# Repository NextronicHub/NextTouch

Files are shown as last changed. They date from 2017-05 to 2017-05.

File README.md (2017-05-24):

# Nextronic NextTouch

The NextTouch is a microcontroller board based on the ATmega32u4. It has 20 digital input/output pins (of which 7 can be used as PWM outputs and 12 as analog inputs), a 16 MHz crystal oscillator, a micro USB connection, and a ICSP header. It contains everything needed to support the microcontroller; simply connect it to a computer with a USB cable and get started. 

the ATmega32u4 has built-in USB communication, eliminating the need for a secondary processor. This allows the NextTouch to appear to a connected computer as a mouse and keyboard, in addition to a virtual (CDC) serial / COM port. It also has other implications for the behavior of the board.

Using the NextTouch you can make anything into a key just by connecting a few alligator clips. This allows you to hook up all kinds of fun things as an input.
The NextTouch uses high resistance switching to detect when you've made a connection even through materials that aren't very conductive (like leaves, pasta or people).

## Features

  ATmega32U4 microcontroller w<br />
  Input voltage 5V<br />
  0-5V outputs<br />
  18 Digital capacitive inputs Pins <br />
  6 Analog Inputs<br />
  I2C, UART and SPI<br />
  32k Flash Memory<br />
  16MHz Clock Speed<br />

<br />
<br />

Nextronic Product page:[NextTouch](http://nextronic.ma/product/nextTouch/).

you can by it at: [makershop.ma](http://makershop.ma/).

## Repository Contents

/Hardware - Design files (.brd, .sch)  
/Firmware - bootloader  
/Documentation - datasheet and examples

## Product Versions

NextTouch_V1 first release

## License Information

The hardware is released under [Creative Commons ShareAlike 4.0 International](https://creativecommons.org/licenses/by-sa/4.0/).

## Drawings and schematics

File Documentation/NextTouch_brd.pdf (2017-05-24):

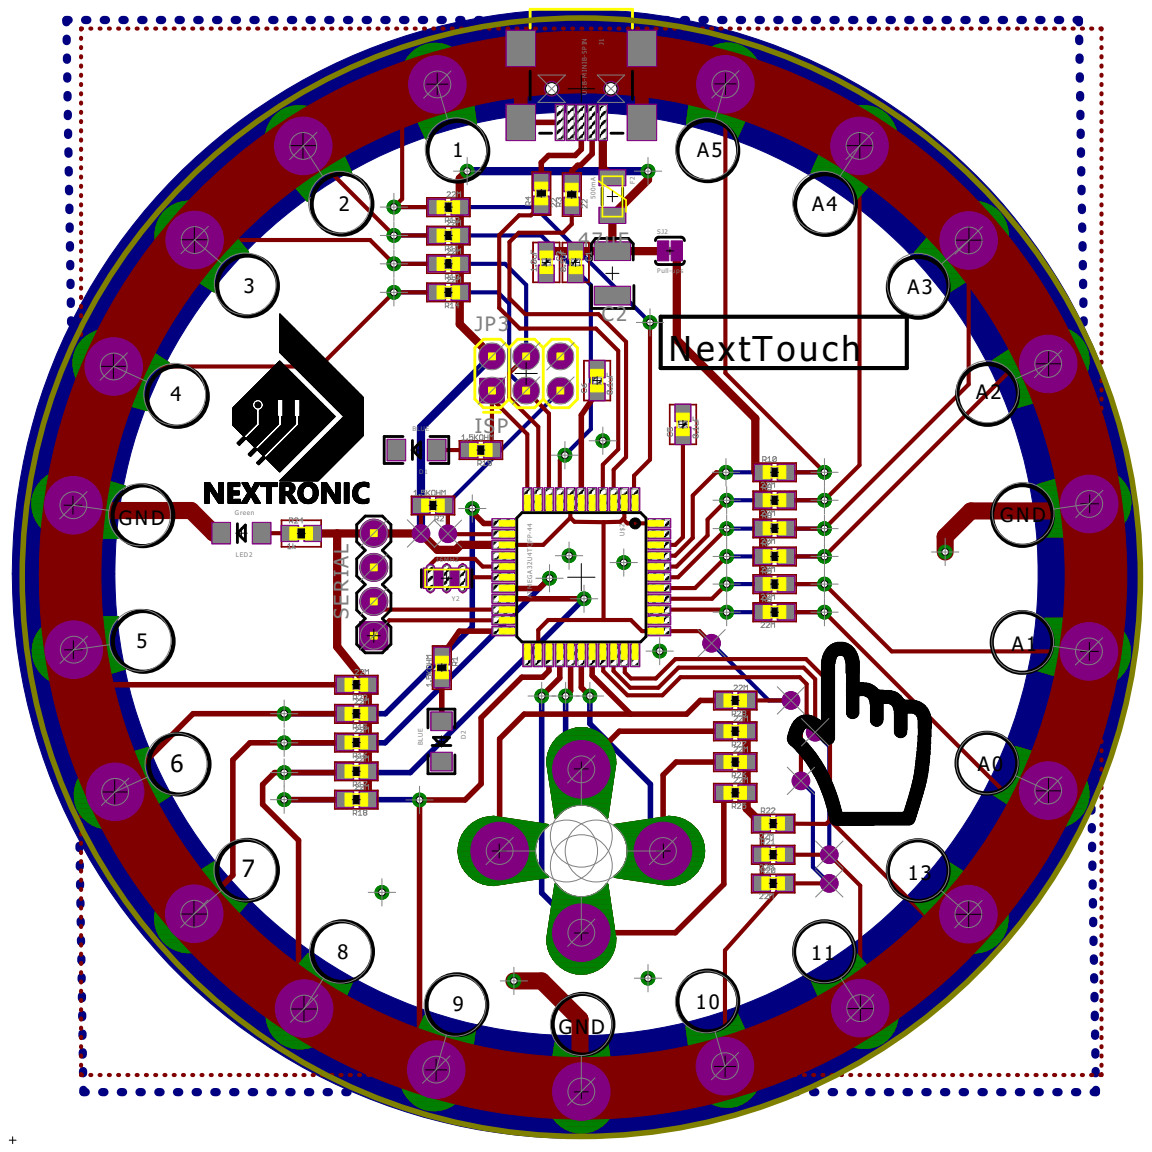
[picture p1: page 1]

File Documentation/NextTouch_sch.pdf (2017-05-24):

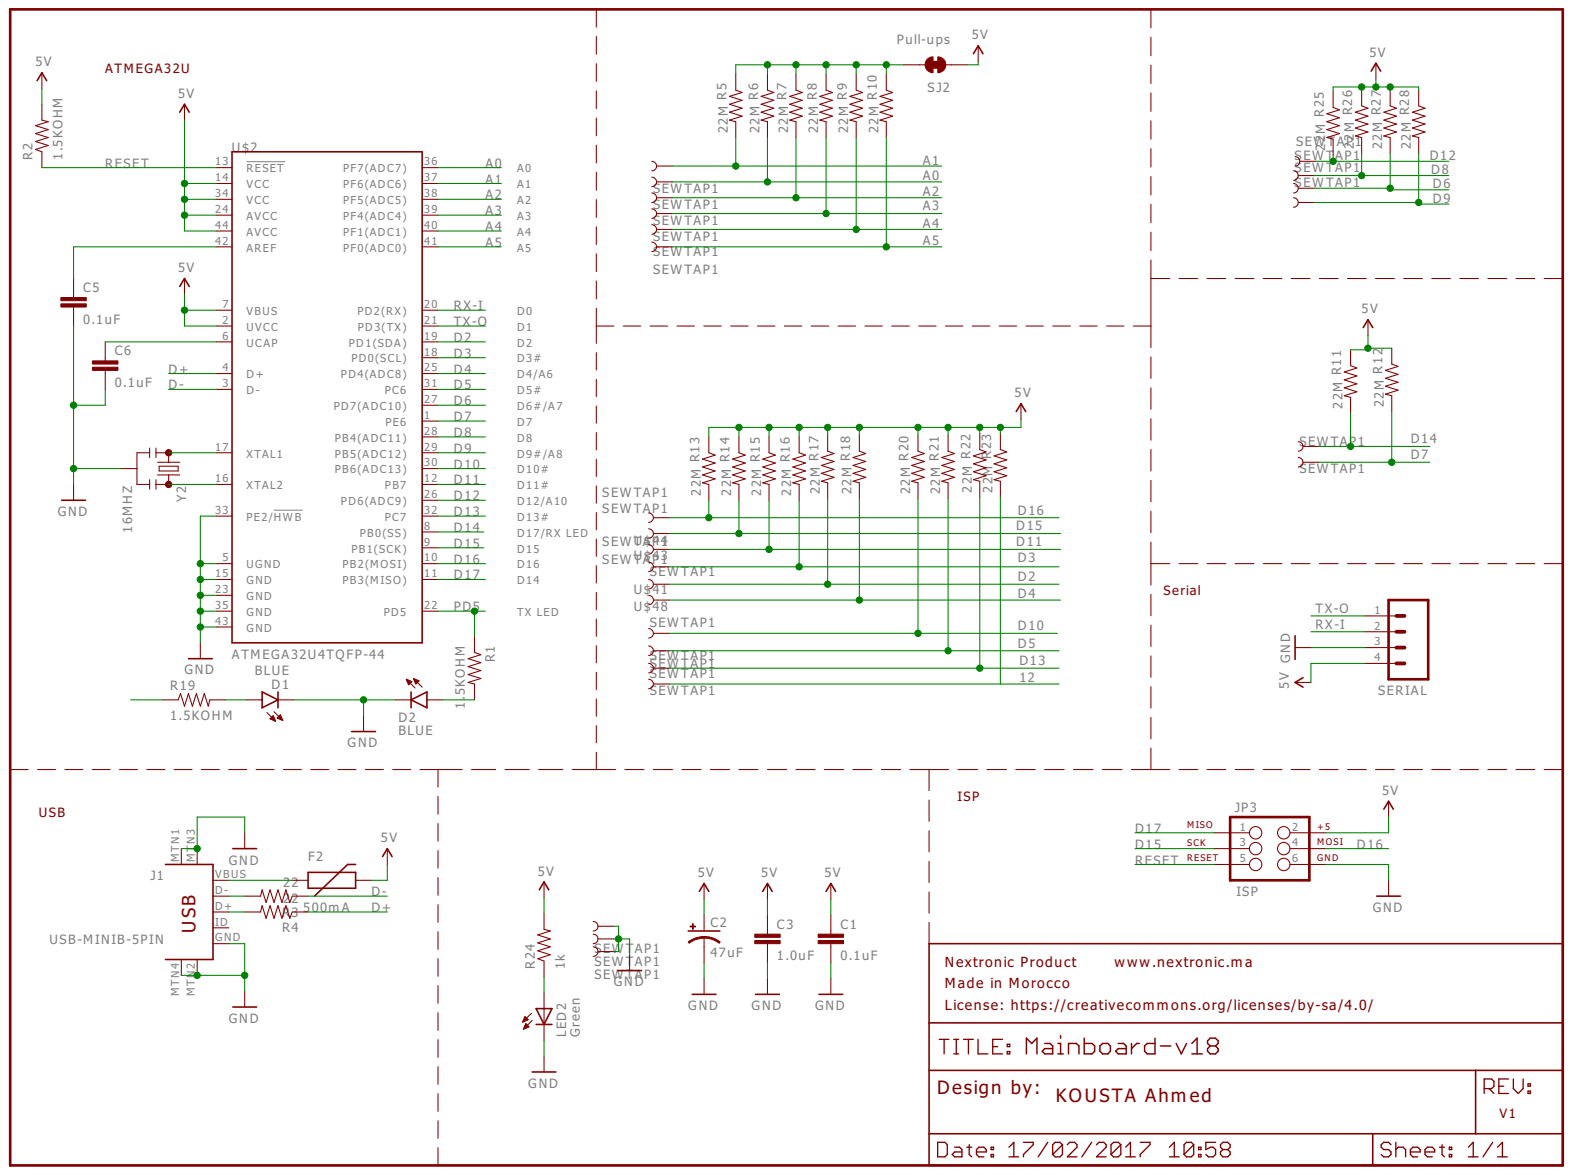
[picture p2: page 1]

SEW TAP1 SEW TAP1

SEW TAP1

License: https://creativecommons.org/licenses/by-sa/4.0/

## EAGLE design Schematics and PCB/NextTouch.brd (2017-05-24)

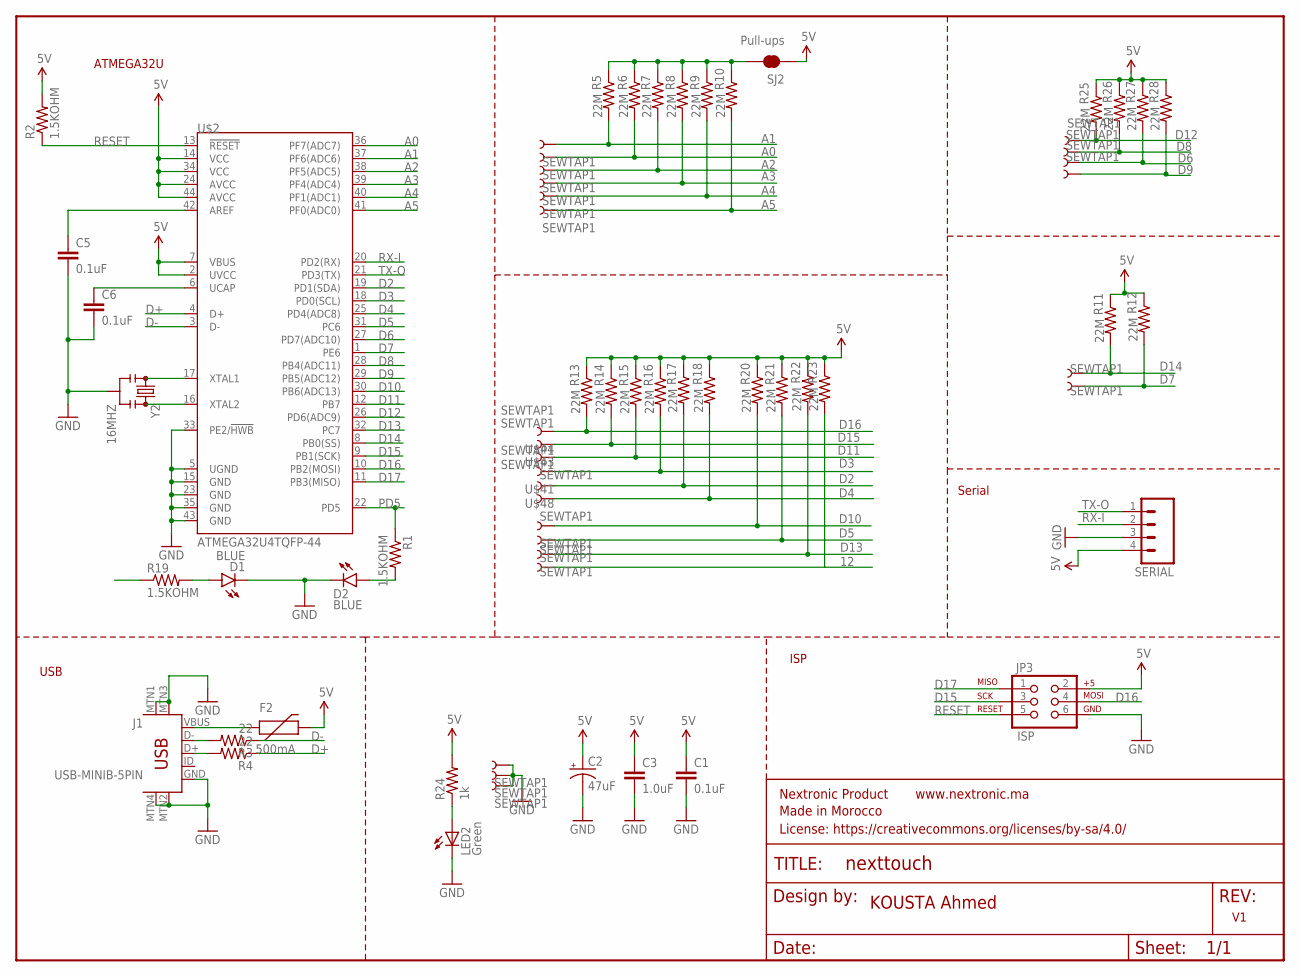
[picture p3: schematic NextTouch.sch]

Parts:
C1, C5, C6: 0.1uF; 0603
C2: 47uF; EIA3528
C3: 1.0uF; 0603
D1, D2: BLUE; LED-1206
F2: 500mA; PTC-1206
FRAME1: FRAME-LETTER; CREATIVE_COMMONS
GND: SEWTAP1; PETAL-LONG-1
J1: USB-MINIB-5PIN; USB-MINIB
JP3: ISP; 2X3-NS
LED2: Green; LED-1206-NO_SILK
R1, R2, R19: 1.5KOHM; 0603
R3, R4: 22; 0603
R5, R6, R7, R8, R9, R10, R11, R12, R13, R14, R15, R16, R17, R18, R20, R21, R22, R23, R25, R26, R27, R28: 22M; 0603
R24: 1k; 0603-RES
SERIAL: M04PTH; 1X04
SJ2: Pull-ups; SJ_2S-TRACE
U$2: ATMEGA32U4TQFP-44; TQFP44
U$3, U$4, U$5, U$6, U$7, U$30, U$31, U$32, U$33, U$34, U$35, U$36, U$37, U$38, U$39, U$40, U$41, U$42, U$43, U$44, U$45, U$46, U$48, U$51: SEWTAP1; PETAL-LONG-1
Y2: 16MHZ; RESONATOR-SMD

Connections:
5V: C1.1, C2.A (+), C3.1, F2.2, JP3.2, R2.2, R11.1, R12.1, R13.1, R14.1, R15.1, R16.1, R17.1, R18.1, R20.1, R21.1, R22.1, R23.1, R24.2, R25.1, R26.1, R27.1, R28.1, SERIAL.4, SJ2.1, U$2.2 (UVCC), U$2.7 (VBUS), U$2.14 (VCC), U$2.24 (AVCC), U$2.34 (VCC), U$2.44 (AVCC)
12: R23.2, U$51.1
A0: R6.2, U$2.36 (PF7(ADC7)), U$40.1
A1: R5.2, U$2.37 (PF6(ADC6)), U$4.1
A2: R7.2, U$2.38 (PF5(ADC5)), U$31.1
A3: R8.2, U$2.39 (PF4(ADC4)), U$32.1
A4: R9.2, U$2.40 (PF1(ADC1)), U$33.1
A5: R10.2, U$2.41 (PF0(ADC0)), U$34.1
D2: R17.2, U$2.19 (PD1(SDA)), U$48.1
D3: R16.2, U$2.18 (PD0(SCL)), U$41.1
D4: R18.2, U$2.25 (PD4(ADC8)), U$35.1
D5: R21.2, U$2.31 (PC6), U$38.1
D6: R27.2, U$2.27 (PD7(ADC10)), U$7.1
D7: R12.2, U$2.1 (PE6), U$46.1
D8: R26.2, U$2.28 (PB4(ADC11)), U$6.1
D9: R28.2, U$2.29 (PB5(ADC12)), U$3.1
D10: R20.2, U$2.30 (PB6(ADC13)), U$37.1
D11: R15.2, U$2.12 (PB7), U$42.1
D12: R25.2, U$2.26 (PD6(ADC9)), U$5.1
D13: R22.2, U$2.32 (PC7), U$39.1
D14: R11.2, U$2.8 (PB0(SS)), U$45.1
D15: JP3.3, R14.2, U$2.9 (PB1(SCK)), U$43.1
D16: JP3.4, R13.2, U$2.10 (PB2(MOSI)), U$44.1
D17: JP3.1, R19.1, U$2.11 (PB3(MISO))
D+: R4.1, U$2.4 (D+)
D-: R3.1, U$2.3 (D-)
GND: C1.2, C2.C (-), C3.2, C5.2, C6.2, D1.C, D2.C, GND.1, J1.GND, J1.MTN1 (MTN2), J1.MTN2 (MTN3), J1.MTN3 (MTN1), J1.MTN4, JP3.6, LED2.C, SERIAL.3, U$2.5 (UGND), U$2.15 (GND), U$2.23 (GND), U$2.33 (PE2/!HWB), U$2.35 (GND), U$2.43 (GND), U$30.1, U$36.1, Y2.2
unnamed: D2.A, R1.2
unnamed: LED2.A, R24.1
unnamed: D1.A, R19.2
unnamed: U$2.17 (XTAL1), Y2.1
unnamed: U$2.16 (XTAL2), Y2.3
unnamed: C5.1, U$2.42 (AREF)
unnamed: R5.1, R6.1, R7.1, R8.1, R9.1, R10.1, SJ2.2
unnamed: F2.1, J1.VBUS
unnamed: C6.1, U$2.6 (UCAP)
unnamed: J1.D-, R3.2
unnamed: J1.D+, R4.2
PD5: R1.1, U$2.22 (PD5)
RESET: JP3.5, R2.1, U$2.13 (!RESET)
RX-I: SERIAL.2, U$2.20 (PD2(RX))
TX-O: SERIAL.1, U$2.21 (PD3(TX))

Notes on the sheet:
ATMEGA32U
USB
KOUSTA Ahmed
ISP
Serial

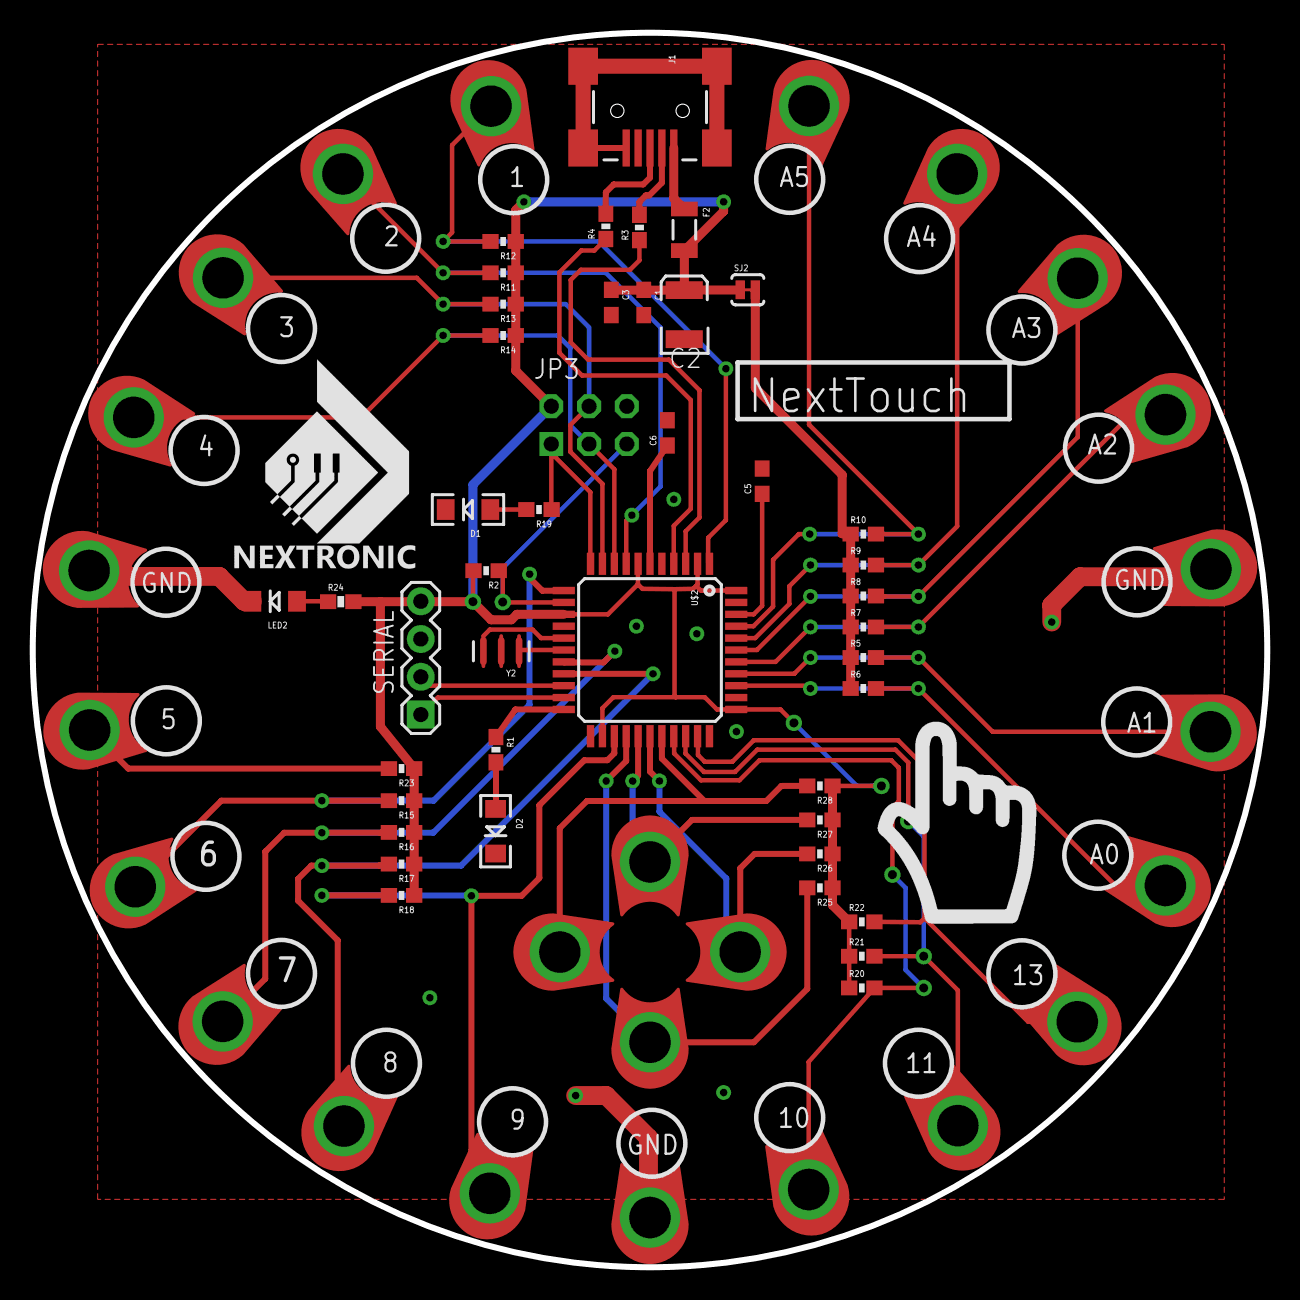
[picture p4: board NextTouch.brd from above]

Board: 2 copper layers, 83.0 x 83.0 mm, 69 parts (0 on the bottom side), 42 nets.

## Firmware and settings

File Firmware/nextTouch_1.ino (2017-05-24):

/*
 ************************************************
 ************** NextTouch *********************
 ************************************************
 
 /////////////////////////////////////////////////
 /////////////HOW TO EDIT THE KEYS ///////////////
 /////////////////////////////////////////////////
 - Edit keys in the settings.h file
 - that file should be open in a tab above (in Arduino IDE)
 - more instructions are in that file
 
 ////////////////////////////////////////////////
 //////// NextTouch FIRMWARE v1.2 /////////////
 ////////////////////////////////////////////////
 by: Ahmed KOUSTA
 Nextronic.ma
 current release: 22/5/2017
 NextTouch FIRMWARE based on the makey makey FIRMWARE v1.4
 */

/////////////////////////
// DEBUG DEFINITIONS ////               
/////////////////////////
//#define DEBUG
//#define DEBUG2 
//#define DEBUG3 
//#define DEBUG_TIMING
//#define DEBUG_MOUSE
//#define DEBUG_TIMING2

////////////////////////
// DEFINED CONSTANTS////
////////////////////////

#define BUFFER_LENGTH    3     // 3 bytes gives us 24 samples
#define NUM_INPUTS       18    // 6 on the front + 12 on the back
//#define TARGET_LOOP_TIME 694   // (1/60 seconds) / 24 samples = 694 microseconds per sample 
//#define TARGET_LOOP_TIME 758  // (1/55 seconds) / 24 samples = 758 microseconds per sample 
#define TARGET_LOOP_TIME 744  // (1/56 seconds) / 24 samples = 744 microseconds per sample 

// id numbers for mouse movement inputs (used in settings.h)
#define MOUSE_MOVE_UP       -1 
#define MOUSE_MOVE_DOWN     -2
#define MOUSE_MOVE_LEFT     -3
#define MOUSE_MOVE_RIGHT    -4

#include <Keyboard.h>
#include <Mouse.h>
#include "settings.h"

/////////////////////////
// STRUCT ///////////////
/////////////////////////
typedef struct {
  byte pinNumber;
  int keyCode;
  byte measurementBuffer[BUFFER_LENGTH]; 
  boolean oldestMeasurement;
  byte bufferSum;
  boolean pressed;
  boolean prevPressed;
  boolean isMouseMotion;
  boolean isMouseButton;
  boolean isKey;
} 
MakeyMakeyInput;

MakeyMakeyInput inputs[NUM_INPUTS];

///////////////////////////////////
// VARIABLES //////////////////////
///////////////////////////////////
int bufferIndex = 0;
byte byteCounter = 0;
byte bitCounter = 0;
int mouseMovementCounter = 0; // for sending mouse movement events at a slower interval

int pressThreshold;
int releaseThreshold;
boolean inputChanged;

int mouseHoldCount[NUM_INPUTS]; // used to store mouse movement hold data

// Pin Numbers
// input pin numbers for kickstarter production board
int pinNumbers[NUM_INPUTS] = {
  6, 12, 9, 8,                         // Arrows pinout setup
  7, 15, 11, 3, 2, 4, 10, 5, 13,       // alphabets pinout setup
  //A0, A1, A2, A3, A4, A5             // mouse pinout setup
};

// input status LED pin numbers
const int inputLED_a = 9;
const int inputLED_b = 10;
const int inputLED_c = 11;
const int outputK = 14;
const int outputM = 16;
byte ledCycleCounter = 0;

// timing
int loopTime = 0;
int prevTime = 0;
int loopCounter = 0;


///////////////////////////
// FUNCTIONS //////////////
///////////////////////////
void initializeArduino();
void initializeInputs();
void updateMeasurementBuffers();
void updateBufferSums();
void updateBufferIndex();
void updateInputStates();
void sendMouseButtonEvents();
void sendMouseMovementEvents();
void addDelay();
void cycleLEDs();
void danceLeds();
void updateOutLEDs();

//////////////////////
// SETUP /////////////
//////////////////////
void setup() 
{
  initializeArduino();
  initializeInputs();
  danceLeds();
}

////////////////////
// MAIN LOOP ///////
////////////////////
void loop() 
{
  updateMeasurementBuffers();
  updateBufferSums();
  updateBufferIndex();
  updateInputStates();
  sendMouseButtonEvents();
  sendMouseMovementEvents();
  cycleLEDs();
  updateOutLEDs();
  addDelay();
}

//////////////////////////
// INITIALIZE ARDUINO
//////////////////////////
void initializeArduino() {
#ifdef DEBUG
  Serial.begin(9600);  // Serial for debugging
#endif

  /* Set up input pins 
   DEactivate the internal pull-ups, since we're using external resistors */
  for (int i=0; i<NUM_INPUTS; i++)
  {
    pinMode(pinNumbers[i], INPUT);
    digitalWrite(pinNumbers[i], LOW);
  }

  pinMode(inputLED_a, INPUT);
  pinMode(inputLED_b, INPUT);
  pinMode(inputLED_c, INPUT);
  digitalWrite(inputLED_a, LOW);
  digitalWrite(inputLED_b, LOW);
  digitalWrite(inputLED_c, LOW);

  pinMode(outputK, OUTPUT);
  pinMode(outputM, OUTPUT);
  digitalWrite(outputK, LOW);
  digitalWrite(outputM, LOW);


#ifdef DEBUG
  delay(4000); // allow us time to reprogram in case things are freaking out
#endif

  Keyboard.begin();
  Mouse.begin();
}

///////////////////////////
// INITIALIZE INPUTS
///////////////////////////
void initializeInputs() {

  float thresholdPerc = SWITCH_THRESHOLD_OFFSET_PERC;
  float thresholdCenterBias = SWITCH_THRESHOLD_CENTER_BIAS/50.0;
  float pressThresholdAmount = (BUFFER_LENGTH * 8) * (thresholdPerc / 100.0);
  float thresholdCenter = ( (BUFFER_LENGTH * 8) / 2.0 ) * (thresholdCenterBias);
  pressThreshold = int(thresholdCenter + pressThresholdAmount);
  releaseThreshold = int(thresholdCenter - pressThresholdAmount);

#ifdef DEBUG
  Serial.println(pressThreshold);
  Serial.println(releaseThreshold);
#endif

  for (int i=0; i<NUM_INPUTS; i++) {
    inputs[i].pinNumber = pinNumbers[i];
    inputs[i].keyCode = keyCodes[i];

    for (int j=0; j<BUFFER_LENGTH; j++) {
      inputs[i].measurementBuffer[j] = 0;
    }
    inputs[i].oldestMeasurement = 0;
    inputs[i].bufferSum = 0;

    inputs[i].pressed = false;
    inputs[i].prevPressed = false;

    inputs[i].isMouseMotion = false;
    inputs[i].isMouseButton = false;
    inputs[i].isKey = false;

    if (inputs[i].keyCode < 0) {
#ifdef DEBUG_MOUSE
      Serial.println("GOT IT");  
#endif

      inputs[i].isMouseMotion = true;
    } 
    else if ((inputs[i].keyCode == MOUSE_LEFT) || (inputs[i].keyCode == MOUSE_RIGHT)) {
      inputs[i].isMouseButton = true;
    } 
    else {
      inputs[i].isKey = true;
    }
#ifdef DEBUG
    Serial.println(i);
#endif

  }
}


//////////////////////////////
// UPDATE MEASUREMENT BUFFERS
//////////////////////////////
void updateMeasurementBuffers() {

  for (int i=0; i<NUM_INPUTS; i++) {

    // store the oldest measurement, which is the one at the current index,
    // before we update it to the new one 
    // we use oldest measurement in updateBufferSums
    byte currentByte = inputs[i].measurementBuffer[byteCounter];
    inputs[i].oldestMeasurement = (currentByte >> bitCounter) & 0x01; 

    // make the new measurement
    boolean newMeasurement = digitalRead(inputs[i].pinNumber);

    // invert so that true means the switch is closed
    newMeasurement = !newMeasurement; 

    // store it    
    if (newMeasurement) {
      currentByte |= (1<<bitCounter);
    } 
    else {
      currentByte &= ~(1<<bitCounter);
    }
    inputs[i].measurementBuffer[byteCounter] = currentByte;
  }
}

///////////////////////////
// UPDATE BUFFER SUMS
///////////////////////////
void updateBufferSums() {

  // the bufferSum is a running tally of the entire measurementBuffer
  // add the new measurement and subtract the old one

  for (int i=0; i<NUM_INPUTS; i++) {
    byte currentByte = inputs[i].measurementBuffer[byteCounter];
    boolean currentMeasurement = (currentByte >> bitCounter) & 0x01; 
    if (currentMeasurement) {
      inputs[i].bufferSum++;
    }
    if (inputs[i].oldestMeasurement) {
      inputs[i].bufferSum--;
    }
  }  
}

///////////////////////////
// UPDATE BUFFER INDEX
///////////////////////////
void updateBufferIndex() {
  bitCounter++;
  if (bitCounter == 8) {
    bitCounter = 0;
    byteCounter++;
    if (byteCounter == BUFFER_LENGTH) {
      byteCounter = 0;
    }
  }
}

///////////////////////////
// UPDATE INPUT STATES
///////////////////////////
void updateInputStates() {
  inputChanged = false;
  for (int i=0; i<NUM_INPUTS; i++) {
    inputs[i].prevPressed = inputs[i].pressed; // store previous pressed state (only used for mouse buttons)
    if (inputs[i].pressed) {
      if (inputs[i].bufferSum < releaseThreshold) {  
        inputChanged = true;
        inputs[i].pressed = false;
        if (inputs[i].isKey) {
          Keyboard.release(inputs[i].keyCode);
        }
        if (inputs[i].isMouseMotion) {  
          mouseHoldCount[i] = 0;  // input becomes released, reset mouse hold
        }
      }
      else if (inputs[i].isMouseMotion) {  
        mouseHoldCount[i]++; // input remains pressed, increment mouse hold
      }
    } 
    else if (!inputs[i].pressed) {
      if (inputs[i].bufferSum > pressThreshold) {  // input becomes pressed
        inputChanged = true;
        inputs[i].pressed = true; 
        if (inputs[i].isKey) {
          Keyboard.press(inputs[i].keyCode);
        }
      }
    }
  }
#ifdef DEBUG3
  if (inputChanged) {
    Serial.println("change");
  }
#endif
}

/*
///////////////////////////
 // SEND KEY EVENTS (obsolete, used in versions with pro micro bootloader)
 ///////////////////////////
 void sendKeyEvents() {
 if (inputChanged) {
 KeyReport report = {
 0                                                        };
 for (int i=0; i<6; i++) {
 report.keys[i] = 0;
 } 
 int count = 0;
 for (int i=0; i<NUM_INPUTS; i++) {
 if (inputs[i].pressed && (count < 6)) {
 report.keys[count] = inputs[i].keyCode;
 
 #ifdef DEBUG3
 Serial.println(report.keys[count]);
 #endif
 
 count++;        
 }
 }
 if (count > 0) {
 report.modifiers = 0x00;
 report.reserved = 1;
 Keyboard.sendReport(&report);
 } 
 else {
 report.modifiers = 0x00;
 report.reserved = 0;
 Keyboard.sendReport(&report);
 }      
 } 
 else {
 // might need a delay here to compensate for the time it takes to send keyreport
 }
 }
 */

/////////////////////////////
// SEND MOUSE BUTTON EVENTS 
/////////////////////////////
void sendMouseButtonEvents() {
  if (inputChanged) {
    for (int i=0; i<NUM_INPUTS; i++) {
      if (inputs[i].isMouseButton) {
        if (inputs[i].pressed) {
          if (inputs[i].keyCode == MOUSE_LEFT) {
            Mouse.press(MOUSE_LEFT);
          } 
          if (inputs[i].keyCode == MOUSE_RIGHT) {
            Mouse.press(MOUSE_RIGHT);
          } 
        } 
        else if (inputs[i].prevPressed) {
          if (inputs[i].keyCode == MOUSE_LEFT) {
            Mouse.release(MOUSE_LEFT);
          } 
          if (inputs[i].keyCode == MOUSE_RIGHT) {
            Mouse.release(MOUSE_RIGHT);
          }           
        }
      }
    }
  }
}

//////////////////////////////
// SEND MOUSE MOVEMENT EVENTS
//////////////////////////////
void sendMouseMovementEvents() {
  byte right = 0;
  byte left = 0;
  byte down = 0;
  byte up = 0;
  byte horizmotion = 0;
  byte vertmotion = 0;

  mouseMovementCounter++;
  mouseMovementCounter %= MOUSE_MOTION_UPDATE_INTERVAL;
  if (mouseMovementCounter == 0) {
    for (int i=0; i<NUM_INPUTS; i++) {
#ifdef DEBUG_MOUSE
      //  Serial.println(inputs[i].isMouseMotion);  
#endif

      if (inputs[i].isMouseMotion) {
        if (inputs[i].pressed) {
          if (inputs[i].keyCode == MOUSE_MOVE_UP) {
            // JL Changes (x4): now update to 1 + a hold factor, constrained between 1 and mouse max movement speed
            up=constrain(1+mouseHoldCount[i]/MOUSE_RAMP_SCALE, 1, MOUSE_MAX_PIXELS);
          }  
          if (inputs[i].keyCode == MOUSE_MOVE_DOWN) {
            down=constrain(1+mouseHoldCount[i]/MOUSE_RAMP_SCALE, 1, MOUSE_MAX_PIXELS);
          }  
          if (inputs[i].keyCode == MOUSE_MOVE_LEFT) {
            left=constrain(1+mouseHoldCount[i]/MOUSE_RAMP_SCALE, 1, MOUSE_MAX_PIXELS);
          }  
          if (inputs[i].keyCode == MOUSE_MOVE_RIGHT) {
            right=constrain(1+mouseHoldCount[i]/MOUSE_RAMP_SCALE, 1, MOUSE_MAX_PIXELS);
          }  
        }
      }
    }

    // diagonal scrolling and left/right cancellation
    if(left > 0)
    {
      if(right > 0)
      {
        horizmotion = 0; // cancel horizontal motion because left and right are both pushed
      }
      else
      {
        horizmotion = -left; // left yes, right no
      }
    }
    else
    {
      if(right > 0)
      {
        horizmotion = right; // right yes, left no
      }
    }

    if(down > 0)
    {
      if(up > 0)
      {
        vertmotion = 0; // cancel vertical motion because up and down are both pushed
      }
      else
      {
        vertmotion = down; // down yes, up no
      }
    }
    else
    {
      if (up > 0)
      {
        vertmotion = -up; // up yes, down no
      }
    }
    // now move the mouse
    if( !((horizmotion == 0) && (vertmotion==0)) )
    {
      Mouse.move(horizmotion * PIXELS_PER_MOUSE_STEP, vertmotion * PIXELS_PER_MOUSE_STEP);
    }
  }
}

///////////////////////////
// ADD DELAY
///////////////////////////
void addDelay() {

  loopTime = micros() - prevTime;
  if (loopTime < TARGET_LOOP_TIME) {
    int wait = TARGET_LOOP_TIME - loopTime;
    delayMicroseconds(wait);
  }

  prevTime = micros();

#ifdef DEBUG_TIMING
  if (loopCounter == 0) {
    int t = micros()-prevTime;
    Serial.println(t);
  }
  loopCounter++;
  loopCounter %= 999;
#endif

}

///////////////////////////
// CYCLE LEDS
///////////////////////////
void cycleLEDs() {
  pinMode(inputLED_a, INPUT);
  pinMode(inputLED_b, INPUT);
  pinMode(inputLED_c, INPUT);
  digitalWrite(inputLED_a, LOW);
  digitalWrite(inputLED_b, LOW);
  digitalWrite(inputLED_c, LOW);

  ledCycleCounter++;
  ledCycleCounter %= 6;

  if ((ledCycleCounter == 0) && inputs[0].pressed) {
    pinMode(inputLED_a, INPUT);
    digitalWrite(inputLED_a, HIGH);
    pinMode(inputLED_b, OUTPUT);
    digitalWrite(inputLED_b, HIGH);
    pinMode(inputLED_c, OUTPUT);
    digitalWrite(inputLED_c, LOW);
  }
  if ((ledCycleCounter == 1) && inputs[1].pressed) {
    pinMode(inputLED_a, OUTPUT);
    digitalWrite(inputLED_a, HIGH);
    pinMode(inputLED_b, OUTPUT);
    digitalWrite(inputLED_b, LOW);
    pinMode(inputLED_c, INPUT);
    digitalWrite(inputLED_c, LOW);

  }
  if ((ledCycleCounter == 2) && inputs[2].pressed) {
    pinMode(inputLED_a, OUTPUT);
    digitalWrite(inputLED_a, LOW);
    pinMode(inputLED_b, OUTPUT);
    digitalWrite(inputLED_b, HIGH);
    pinMode(inputLED_c, INPUT);
    digitalWrite(inputLED_c, LOW);
  }
  if ((ledCycleCounter == 3) && inputs[3].pressed) {
    pinMode(inputLED_a, INPUT);
    digitalWrite(inputLED_a, LOW);
    pinMode(inputLED_b, OUTPUT);
    digitalWrite(inputLED_b, LOW);
    pinMode(inputLED_c, OUTPUT);
    digitalWrite(inputLED_c, HIGH);
  }
  if ((ledCycleCounter == 4) && inputs[4].pressed) {
    pinMode(inputLED_a, OUTPUT);
    digitalWrite(inputLED_a, LOW);
    pinMode(inputLED_b, INPUT);
    digitalWrite(inputLED_b, LOW);
    pinMode(inputLED_c, OUTPUT);
    digitalWrite(inputLED_c, HIGH);
  }
  if ((ledCycleCounter == 5) && inputs[5].pressed) {
    pinMode(inputLED_a, OUTPUT);
    digitalWrite(inputLED_a, HIGH);
    pinMode(inputLED_b, INPUT);
    digitalWrite(inputLED_b, LOW);
    pinMode(inputLED_c, OUTPUT);
    digitalWrite(inputLED_c, LOW);
  }

}

///////////////////////////
// DANCE LEDS
///////////////////////////
void danceLeds()
{
  int delayTime = 50;
  int delayTime2 = 100;

  // CIRCLE
  for(int i=0; i<4; i++)
  {
    // UP
    pinMode(inputLED_a, INPUT);
    digitalWrite(inputLED_a, HIGH);
    pinMode(inputLED_b, OUTPUT);
    digitalWrite(inputLED_b, HIGH);
    pinMode(inputLED_c, OUTPUT);
    digitalWrite(inputLED_c, LOW);
    delay(delayTime);

    //RIGHT
    pinMode(inputLED_a, INPUT);
    digitalWrite(inputLED_a, LOW);
    pinMode(inputLED_b, OUTPUT);
    digitalWrite(inputLED_b, LOW);
    pinMode(inputLED_c, OUTPUT);
    digitalWrite(inputLED_c, HIGH);
    delay(delayTime);


    // DOWN
    pinMode(inputLED_a, OUTPUT);
    digitalWrite(inputLED_a, HIGH);
    pinMode(inputLED_b, OUTPUT);
    digitalWrite(inputLED_b, LOW);
    pinMode(inputLED_c, INPUT);
    digitalWrite(inputLED_c, LOW);
    delay(delayTime);

    // LEFT
    pinMode(inputLED_a, OUTPUT);
    digitalWrite(inputLED_a, LOW);
    pinMode(inputLED_b, OUTPUT);    
    digitalWrite(inputLED_b, HIGH);
    pinMode(inputLED_c, INPUT);
    digitalWrite(inputLED_c, LOW);
    delay(delayTime);    
  }    

  // WIGGLE
  for(int i=0; i<4; i++)
  {
    // SPACE
    pinMode(inputLED_a, OUTPUT);
    digitalWrite(inputLED_a, HIGH);
    pinMode(inputLED_b, INPUT);
    digitalWrite(inputLED_b, LOW);
    pinMode(inputLED_c, OUTPUT);
    digitalWrite(inputLED_c, LOW);
    delay(delayTime2);    

    // CLICK
    pinMode(inputLED_a, OUTPUT);
    digitalWrite(inputLED_a, LOW);
    pinMode(inputLED_b, INPUT);
    digitalWrite(inputLED_b, LOW);
    pinMode(inputLED_c, OUTPUT);
    digitalWrite(inputLED_c, HIGH);
    delay(delayTime2);    
  }
}

void updateOutLEDs()
{
  boolean keyPressed = 0;
  boolean mousePressed = 0;

  for (int i=0; i<NUM_INPUTS; i++)
  {
    if (inputs[i].pressed)
    {
      if (inputs[i].isKey)
      {
        keyPressed = 1;
#ifdef DEBUG
        Serial.print("Key ");
        Serial.print(i);
        Serial.println(" pressed");
#endif
      }
      else
      {
        mousePressed = 1;
      }
    }
  }

  if (keyPressed)
  {
    digitalWrite(outputK, HIGH);
    TXLED1;
  }
  else
  {
    digitalWrite(outputK, LOW);
    TXLED0;
  }

  if (mousePressed)
  {
    digitalWrite(outputM, HIGH);
    RXLED1;
  }
  else
  {
    digitalWrite(outputM, LOW);
    RXLED0;
  }
}

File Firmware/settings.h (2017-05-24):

#include "Arduino.h"

/*
/////////////////////////////////////////////////////////////////////////
// KEY MAPPINGS: WHICH KEY MAPS TO WHICH PIN ON THE NextTouch BOARD?  //
/////////////////////////////////////////////////////////////////////////
  
  - edit the keyCodes array below to change the keys sent by the NextTouch for each input
  - the comments tell you which input sends that key 
  - change the keys by replacing them. for example, you can replace 'q' with any other individual letter,
    number, or symbol on your keyboard
  - you can also use codes for other keys such as modifier and function keys 

*/

int keyCodes[NUM_INPUTS] = {
  // Arrows pinout setup
 
  KEY_UP_ARROW,      // Atmega_pin 6       NextTouch_pin    up arrow pad     
  KEY_DOWN_ARROW,    // Atmega_pin 12      NextTouch_pin    down arrow pad
  KEY_LEFT_ARROW,    // Atmega_pin 9       NextTouch_pin    left arrow pad
  KEY_RIGHT_ARROW,   // Atmega_pin 8       NextTouch_pin    right arrow pad
   
  
  // alphabets pinout setup
         
  'q',                // Atmega_pin 7     NextTouch_pin 1
  's',                // Atmega_pin 15    NextTouch_pin 4
  'd',                // Atmega_pin 11    NextTouch_pin 6
  'f',                // Atmega_pin 3     NextTouch_pin 7
  'g',                // Atmega_pin 2     NextTouch_pin 8
  'h',                // Atmega_pin 4     NextTouch_pin 9
  'j',                // Atmega_pin 10    NextTouch_pin 10
  'k',                // Atmega_pin 5     NextTouch_pin 11
  'l',                // Atmega_pin 13    NextTouch_pin 13
 
 // mouse pinout setup

  //MOUSE_MOVE_DOWN,    // Atmega_pin 6       NextTouch_pin    up arrow pad 
  //MOUSE_MOVE_UP,      // Atmega_pin 12      NextTouch_pin    down arrow pad
  //MOUSE_MOVE_LEFT,    // Atmega_pin 9       NextTouch_pin    left arrow pad
  //MOUSE_MOVE_RIGHT,   // Atmega_pin 8       NextTouch_pin    right arrow pad
  //MOUSE_LEFT,         //10
  //MOUSE_RIGHT         //11
};

/*

///////////////////////////
// ADDITIONAL KEY CODES ///
///////////////////////////

- you can use these codes in the keyCodes array above
- to get modifier keys, function keys, etc 

KEY_LEFT_CTRL
KEY_LEFT_SHIFT    
KEY_LEFT_ALT    
KEY_LEFT_GUI    
KEY_RIGHT_CTRL    
KEY_RIGHT_SHIFT   
KEY_RIGHT_ALT 
KEY_RIGHT_GUI   

KEY_BACKSPACE   
KEY_TAB       
KEY_RETURN      
KEY_ESC       
KEY_INSERT      
KEY_DELETE      
KEY_PAGE_UP     
KEY_PAGE_DOWN   
KEY_HOME
KEY_END       
KEY_CAPS_LOCK 
  
KEY_F1        
KEY_F2        
KEY_F3        
KEY_F4        
KEY_F5        
KEY_F6        
KEY_F7        
KEY_F8        
KEY_F9        
KEY_F10
KEY_F11       
KEY_F12     

*/  
                                         
///////////////////////////
// NOISE CANCELLATION /////
///////////////////////////
#define SWITCH_THRESHOLD_OFFSET_PERC  5    // number between 1 and 49
                                           // larger value protects better against noise oscillations, but makes it harder to press and release
                                           // recommended values are between 2 and 20
                                           // default value is 5

#define SWITCH_THRESHOLD_CENTER_BIAS 55   // number between 1 and 99
                                          // larger value makes it easier to "release" keys, but harder to "press"
                                          // smaller value makes it easier to "press" keys, but harder to "release"
                                          // recommended values are between 30 and 70
                                          // 50 is "middle" 2.5 volt center
                                          // default value is 55
                                          // 100 = 5V (never use this high)
                                          // 0 = 0 V (never use this low
                                          

/////////////////////////
// MOUSE MOTION /////////
/////////////////////////
#define MOUSE_MOTION_UPDATE_INTERVAL  35   // how many loops to wait between 
                                           // sending mouse motion updates
                                           
#define PIXELS_PER_MOUSE_STEP         4     // a larger number will make the mouse
                                           // move faster

#define MOUSE_RAMP_SCALE              150  // Scaling factor for mouse movement ramping
                                           // Lower = more sensitive mouse movement
                                           // Higher = slower ramping of speed
                                           // 0 = Ramping off
                                            
#define MOUSE_MAX_PIXELS              10   // Max pixels per step for mouse movement

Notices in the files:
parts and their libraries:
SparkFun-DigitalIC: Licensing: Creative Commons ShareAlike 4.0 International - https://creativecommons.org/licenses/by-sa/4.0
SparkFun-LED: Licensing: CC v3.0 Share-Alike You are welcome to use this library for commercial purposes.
